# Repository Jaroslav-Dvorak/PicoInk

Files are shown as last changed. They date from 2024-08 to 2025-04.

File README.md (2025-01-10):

# PicoInk 

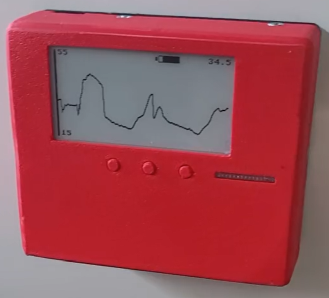
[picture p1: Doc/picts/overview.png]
overview


PicoInk byl vyvinutý za účelem měření fyzikálních veličin v místech, kde není třeba měřit velice často, ale postačuje jedno měření za 15 minut. Například: teplota, výška hladiny, koncentrace CO2, vlhkost půdy, vlhkost vzduchu, a podobně. Z této podstaty byl v návrhu kladen důraz na dlouhou výdrž baterie. 
Oproti podobným zařízením, které využívají deep-sleep režim mikrokontroléru, se zde o periodické měření stará externí časovací obvod [TPL5110](https://www.ti.com/lit/ds/symlink/tpl5110.pdf), který má v odpočítávací fázi téměř neměřitelnou spotřebu (35nA). 
Dalším prvkem, který přispívá k dlouhé výdrži baterie je e-inkový displej, který ze své technické podstaty zobrazuje informace, přestože je baterie odpojena. Za normálních okolností musí displej po připojení k napájení projít tzv. full-refreshem. Full-refresh není příliš estetická záležitost a je také energeticky náročná. Tyto důvody vedly k vývoji knihovny obsluhující displej s možností částečného překreslení i bez full-refreshe.
Horizontální rozlišení použitelného e-ink displeje je 250 pixelů. Pokud využijeme displej k vykreslení průběhu naměřených hodnot, přičemž každá hodnota zabere jeden pixel, můžeme vykreslit historii v grafu v délce necelých tří dnů, konkrétně 62,5 hodin.\
**To z něj v dělá jedinečný bateriový teploměr schopen nepřetržitého zobrazení historie hodnot v grafu.**
Jelikož je mozkem celého zařízení mikrokontrolér Raspberry Pi Pico W, dostupná je konektivita ve formě Bluetooth Low Energy a 2.4GHz WiFi. 
Pro zasílání naměřených hodnot přes Bluetooth byl zvolen otevřený protokol BTHome, ve formě pasivních advertisement zpráv. Důvodem je skvělá kompatibilita a super-rychlá integrace v Home Assistant.
V případě využití WiFi byl zvolen protokol MQTT, který lze rovněž vcelku jednoduše zaintegrovat do Home Assistant systému.\
**Výdrž baterie Liitokala 3500mAh s použitím teplotního a vlhkostního snímače SHT41 s vypnutým vyhříváním a připojení k WiFi s kvalitním signálem byla naměřena na 6 měsíců, cca 10000 měření.**
Baterií je myšlen akumulátor typu 18650, který je možno dobít přes USB-C konektor.
Pro rychlou výměnu lze baterii vyjmout a nahradit baterií čerstvě nabitou.

PicoInk je fyzicky složen ze dvou částí:
* Hlavní část obsahující elektroniku, baterii, displej a desku spojů.
* Modul, který je odnímatelný. Podle jeho typu zařízení plní svůj účel - zde je umístěn snímač.

Spojení mezi těmito částmi zajišťuje konektor, přes který lze modul napájet. Buďto z 3.3V zdroje mikrokontroléru nebo přímo z baterie. 
Dále obsahuje piny, jenž lze použít pro analogové měření nebo sběrnice UART, SPI, I2C, OneWire (viz.doc).
PicoInk je možné po úpravě software využívat i bez modulu. Například pro zobrazování online dat.

**V současné době jsou plně vyvinuty dva moduly - snímač teploty pro horizontální a vertikální bojler.**\
Avšak PicoInk byl otestován a má softwarovou přípravu na: 
* Snímač CO2 SCD41. Výdrž baterie klesla na jeden měsíc (s WiFi).
* Analogový snímač pro kapacitní měření vlhkosti půdy. Vlhkost klesá velmi pomalu, graf je krátký.
* Teplotní a vlhkostní snímač DHT22, měření snímače trvá různou dobu, někdy i velmi dlouho.
* Teplotní a vlhkostní snímač SHT41, vše OK.
* Teplotní snímač Dallas DS18B20, nutné použít originál, jinak vše OK.

**Známé bugy:**\
~~* Při delším vyjmutí baterie dojde k vybití vnitřního kondenzátoru. \
Při opětovném vložení nabitého článku dochází k proudové mikrošpičce. \
Z toho důvodu dojde k deaktivaci výstupu ochranného obvodu. \
Baterii je tedy nutno znovu vytáhnout a vložit. Ve zkratce - **baterii je někdy třeba vložit na dvakrát.**~~\
(Vyřešeno změnou hodnoty kondenzátoru C1 z 1uF na 100nF)

**TODO list:**
- [x] Moduly pro různé bojlery
- [x] Návod k použití pro normální lidi (pdf)
- [x] Tiskové instrukce (README.md ve složce 3D)
- [x] Instrukce ke stavbě zařízení (pdf)
- [x] Instrukce k výměně baterie a montáži/demontáži modulu (pdf)
- [x] Instrukce k naprogramování kontroléru (README.md ve složce Code)
- [x] Instrukce k výrobě PCB (README.md ve složce Electric)

[Zde](https://www.facebook.com/profile.php?id=61566121148711) mě můžete přímo kontaktovat.

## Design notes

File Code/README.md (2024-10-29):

### Instrukce pro naprogramování kontroléru

3. Připojit Rpi Pico W k PC pomocí microUSB kabelu.
2. Do kontroléru nahrát firmware [micropythonu](https://micropython.org/download/RPI_PICO/).
2. Použít k připojení k Rpi Pico W např. [Thonny](https://thonny.org) nebo PyCharm s Micropython pluginem.
3. Flash obsah celého (tohoto) adresáře "Code" do RpiPico W 
   * vyjma souboru README.md
   * můžeme také vynechat soubory ze složky sensors dle použitého typu senzoru.

### Výběr typu snímače
1. Ve složce sensors jsou k dispozici různé snímače.
2. V souboru sensor.py - import podle typu sensoru.
3. Dále definice správných pinů apod.

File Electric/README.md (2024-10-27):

### Výroba elektro: 
1. Objednávka součástek podle [partlistu](./Partlist.md).
2. Soubor **Gerber_PCB_PicoInk.zip** obsahuje výrobní data - zaslat soubor výrobci.
3. Osazení PCB podle schématu. 
[Video osazovnání](https://www.youtube.com/watch?v=MjlOoAGtTvY&list=PL2hwsy43ra5UZU4RDyN6xl_J_FKD02n1o) |
[Komentované video](https://www.youtube.com/watch?v=83LGPPGywaA)

### Editace projektu:
1. Registrace na [EasyEDA](https://easyeda.com).
2. V EasyEDA Std designeru vytvořit nový projekt.
3. File --> File Source --> vložit obsah souboru **SCH_PicoInk.json**
4. Design --> Convert Schematic to PCB --> Save
5. File --> File Source --> vložit obsah souboru **PCB_PicoInk.json**

### Schéma:
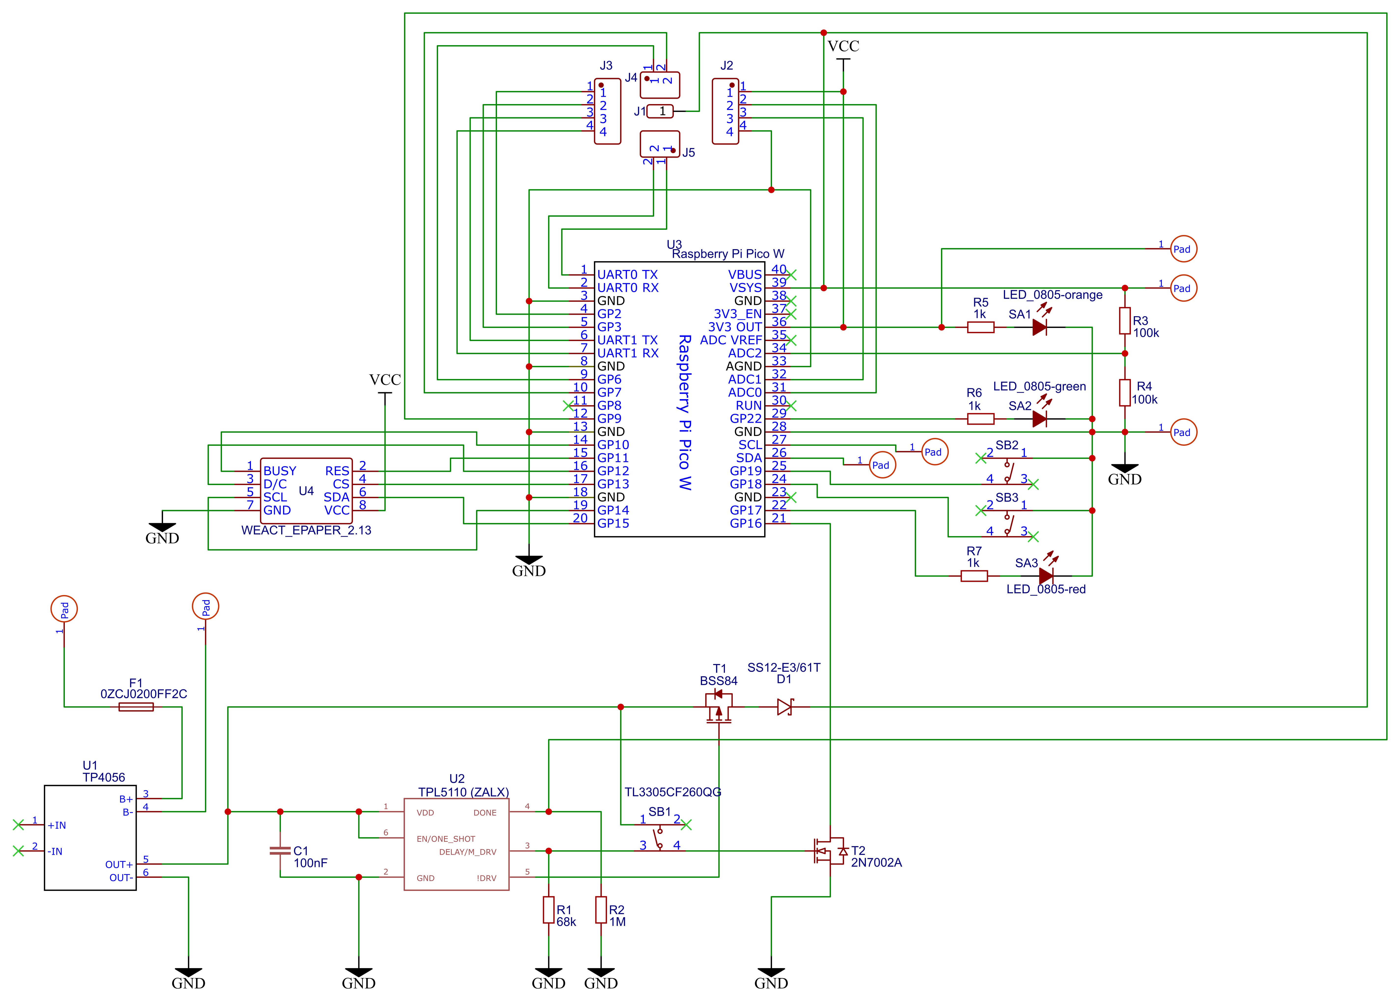
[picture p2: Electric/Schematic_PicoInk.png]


### Konektor:
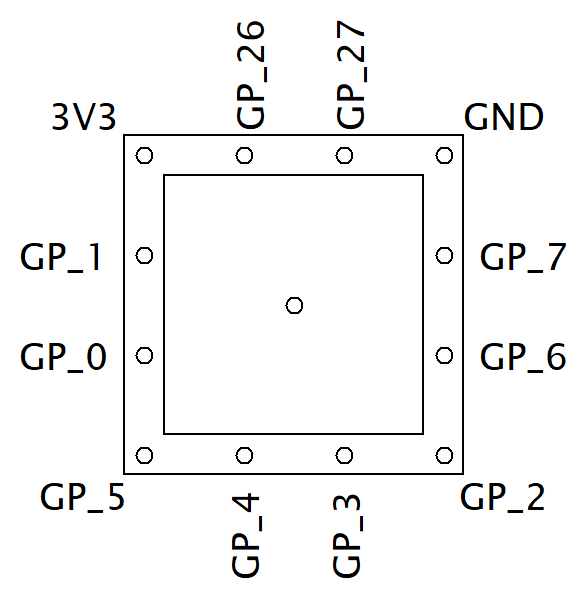
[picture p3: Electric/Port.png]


### PCB:
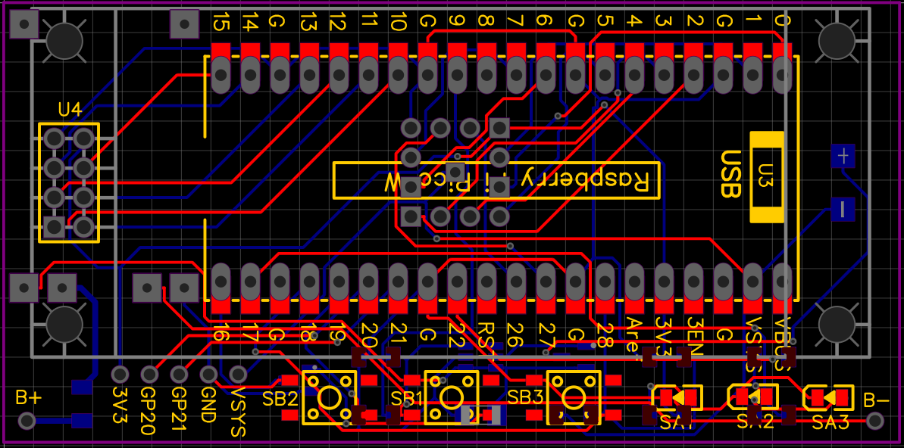
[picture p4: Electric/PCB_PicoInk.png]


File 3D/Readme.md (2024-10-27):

Model byl vytvořen ve FreeCADu, veškeré soubory jsou ve složce "FCStd model".\
Předpřipravené tiskové soubory 3mf byly vytvořeny v Bambu Studiu.\
Modely byly v úspěšně tisknuty na tiskárně Bambulab A1.\

* Základní část zařízení (**MainBody_BambuStudio.3mf**) obsahuje:
  * **main_body** - PLA filament, udává barvu zařízení, základní profil
  * **battery_cover** - PLA filament, doporučena stejná barva jako main_body, základní profil
  * **display_holder** - PLA filament, na barvě nezáleží, základní profil
  * **light_guide** - PETG transparentní, nutný brim

* Modul pro měření teploty Bojleru Dražice (**Modul_Drazice_BambuStudio.3mf**):
    * **spring** - PETG, na barvě nezáleží, základní profil, doporučen 3D Lack
    * **modul** - PETG, barva zadní části zařízení
      * nutný brim
      * tisknout diagonálně
      * manuální supporty podle obrázku
      * variabilní výška vrstvy podle obrázku (0.2 --> 0.12)
      * teplota trysky 260°C

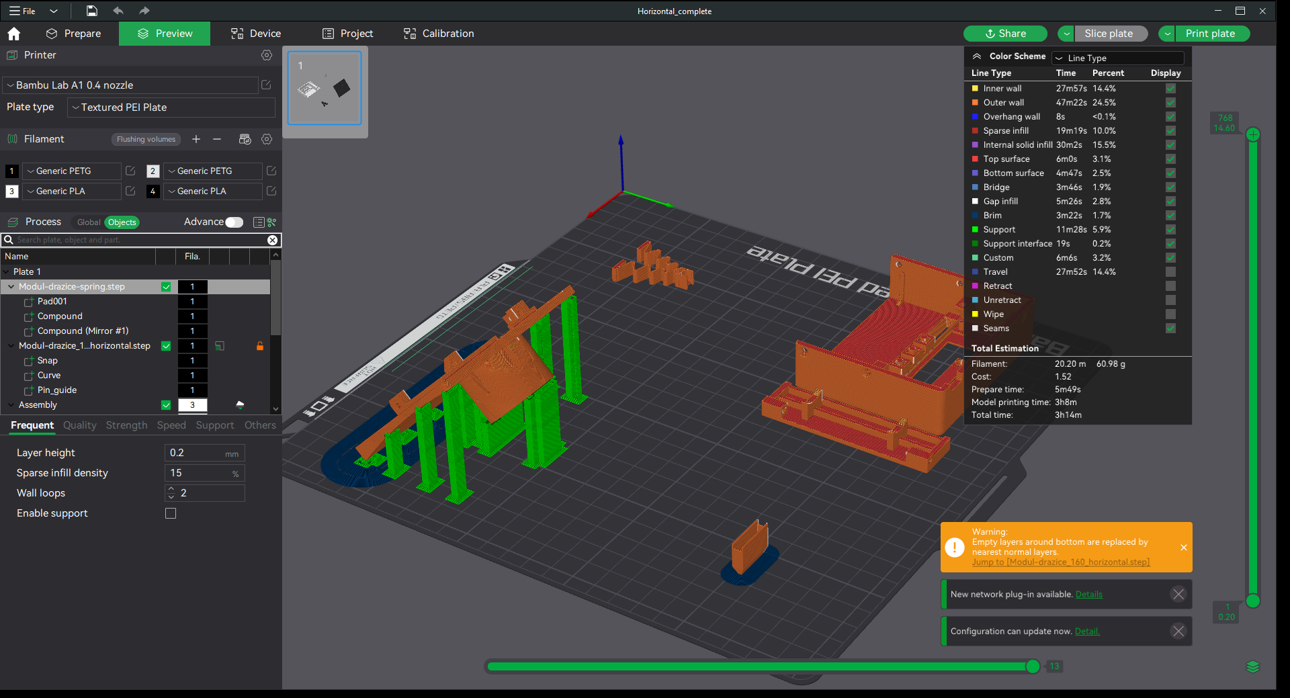
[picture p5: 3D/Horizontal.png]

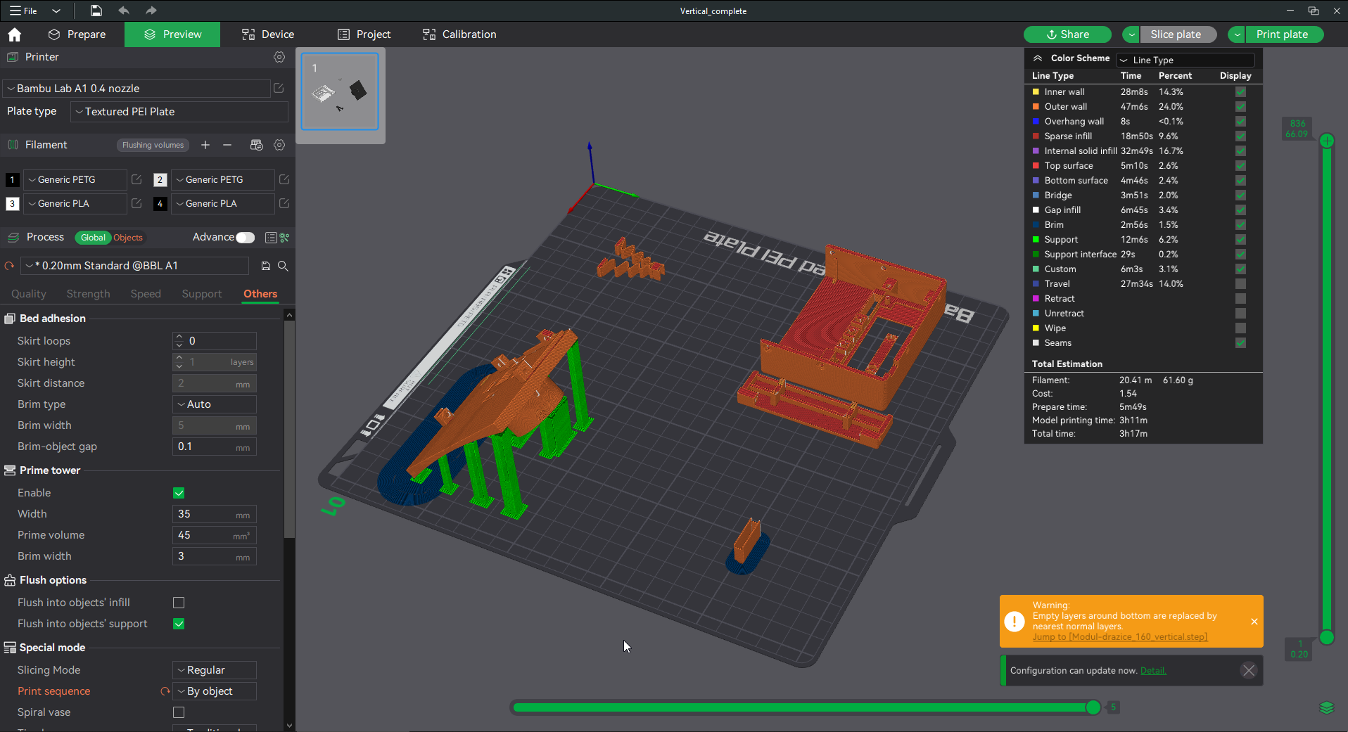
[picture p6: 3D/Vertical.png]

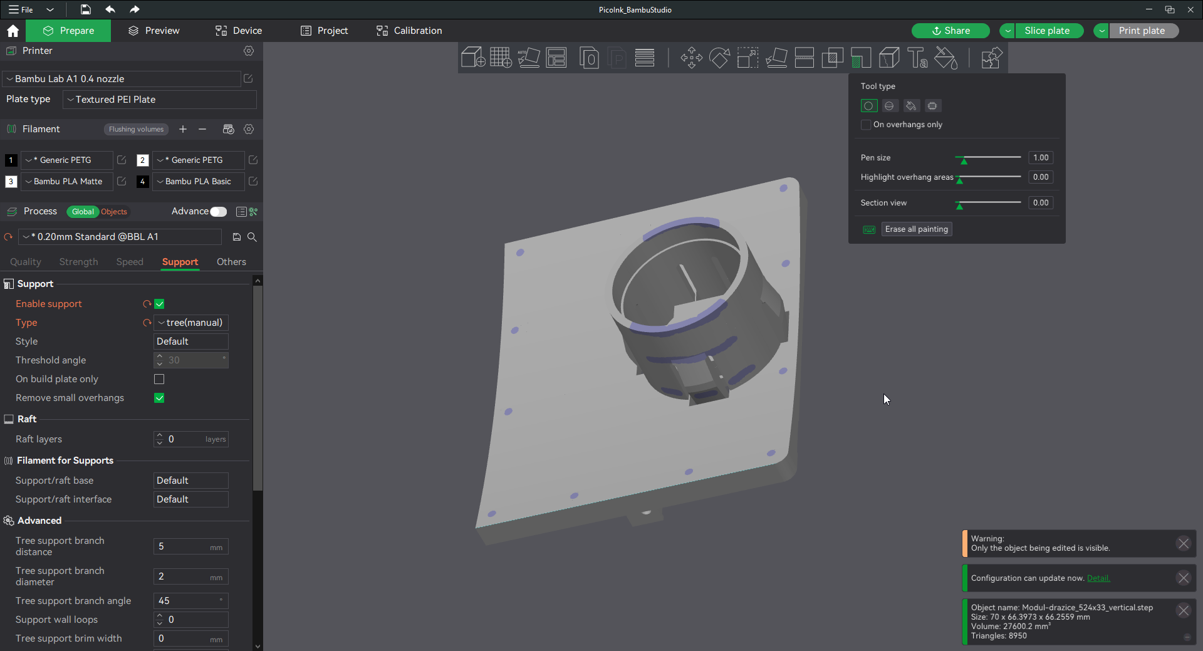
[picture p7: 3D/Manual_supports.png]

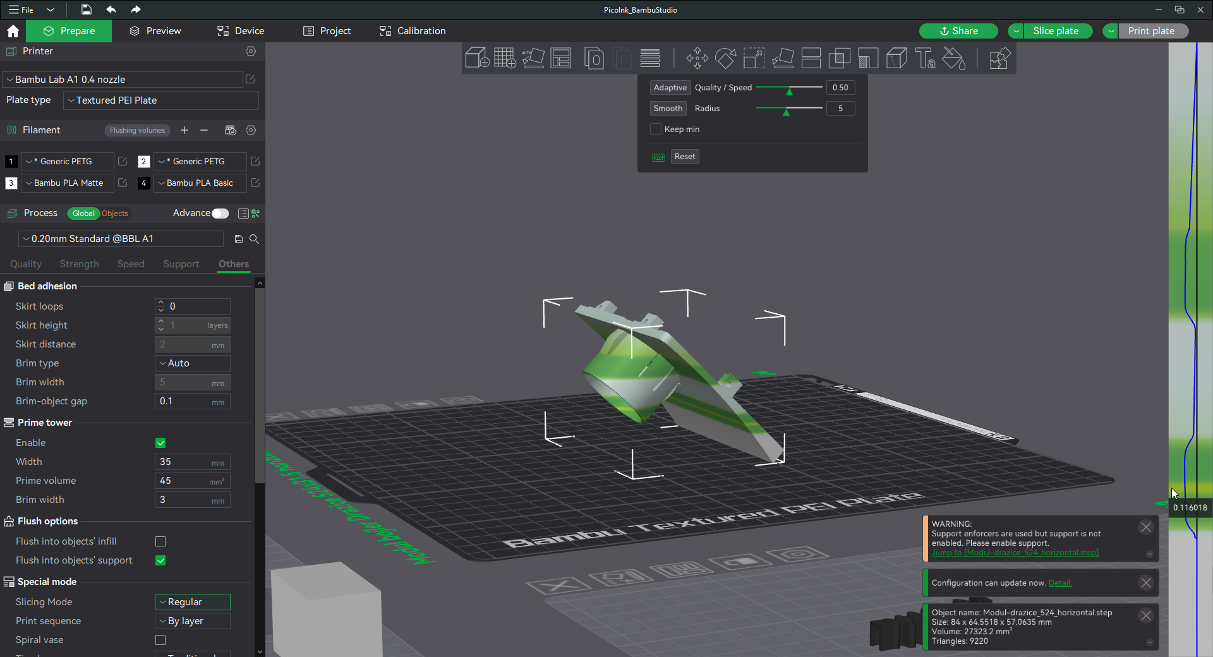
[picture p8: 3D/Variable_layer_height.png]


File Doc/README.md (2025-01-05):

[Manuál - Popis a obsluha zařízení](./PicoInk_control_manual_cs.pdf)\
[Manuál - MQTT nastavení](./PicoInk_MQTT_cs.pdf)\
[Manuál - Stavba zařízení](./PicoInk_assembly_cs.pdf)\
[Manuál - Instalační manuál](./PicoInk_installation_manual_cs.pdf) \
[Video - nastavení zařízení](https://fb.watch/vx8vt5eCgY/)\
[Video - stavba zařízení](https://www.youtube.com/watch?v=83LGPPGywaA)

## Rychlé uvedení do provozu

1. Ujistěte se, že je zařízení funkční. 
   * Krátkým stiskem prostředního tlačítka spustíme běžný cyklus.
   * Stavová LED se rozsvítí oranžově, poté problikne zelená a LED zhasne.
2. Proveďte mechanickou instalaci dle typu modulu.
    * **Modul měření teploty bojleru:**
      * Ujistěte se, že díra připravená pro teploměr je do dostatečné hloubky zbavená přebytečné izolační pěny.
      * Celé zařízení vtlačte do bojleru.
3. Dvojklikem a následným držením prostředního tlačítka vyberte vyhovující grafické zobrazení naměřené hodnoty.
4. Zvažte typ datového připojení. 
   * **Bluetooth Low Energy** s protokolem [BTHome](https://bthome.io):
     * Několikanásobně nižší spotřeba a tím vyšší výdrž baterie.
     * Velmi snadná konfigurace i integrace do Home Assistanta.
     * Žádná zpětná vazba (PicoInk nehlásí žádný problém, pokud datová zpráva nedorazí).
     * Datové zprávy nejsou šifrované a je možné je jednoduše odchytit v okolí senzoru.
   * **WiFi** s protokolem [MQTT](https://mqtt.org):
     * Baterie s kapacitou 3500mAh vydrží zaslání cca 10000 zpráv. Při 15 minutovém intervalu je to cca půl roku.
     * Při nezdařeném odeslání zařízení červeně blikne a na displeji informuje o problému.
     * V zařízení jsou zapsána hesla WiFi a Home Assistanta. Hesla lze vyčíst pomocí kabelového připojení k procesoru.
5. Spusťte nastavovací režim dlouhým podržením levého tlačítka a současným krátkým stiskem prostředního tlačítka.
   * Připojte se k nově vytvořené WiFi (PICOINK) telefonem nebo počítačem.
   * V případě telefonu, naskenujte zobrazený QR kód a potvrďte přesměrování.
   * V případě PC, zadejte do prohlížeče zobrazenou IP adresu (192.168.4.1).
6. Nastavte hodnoty. **Každou změnu je nutno potvrdit tlačítkem Write**.
   * Minimum a Maximum - ovlivňují pouze zobrazení na samotném zařízení (rozsah grafu nebo stupnice).
   * **Bluetooth Low Energy** varianta:
     * Vyplňte pole označené jako BLE-name (název zařízení - např. "bojler").
     * Kliněte na tlačítko Save and restart a zavřete nastavovací stránku.
     * V notifikacích Home Assistantu se zobrazí hlášení o nalezeném novém zařízení. Potvrdíme nakonfigurování do HA.
     * V zařízeních --> BTHome --> můžeme zapnout skrytou entitu signal.
   * **Wifi** varianta:
     * V Home Assistant musí být funkční MQTT integrace. Pokud není postujte podle [tohoto návodu](./PicoInk_MQTT_cs.pdf).
     * **Wifi-SSID** - Název WiFi sítě na kterou se má teploměr připojovat.
     * **WiFi-passw** - WiFi heslo.
     * **WiFi-IP** - nechat prázdné. *Pouze pro zkušené: Statická IP - formát CIDR. Pokud je prázdné, DHCP přidělení.*
     * **MQTT-broker** - IP adresa serveru Home Assistanta (MQTT brokera) nebo jeho DNS název.
     * **MQTT-user** - uživatelské jmeno některého z uživatelů Home Assistanta.
     * **MQTT-passw** - heslo výše zadaného uživatele.
     * **MQTT-name** - název zařízení (součást názvu entit v Home Assistant).
     * Kliněte na tlačítko Save and restart a zavřete nastavovací stránku.
     * Počkejte až zhasne stavová LED.
     * Dlouhým požením pravého tlačítka a současným krátkým stiskem prostředního tlačítka spusťte testovací režim.
     * Pokud hlášení končí "Everything is ok..:-)" V Home Assistantu přibylo nové zařízení s potřebnými entitami.

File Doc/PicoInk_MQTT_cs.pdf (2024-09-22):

Krok 0: Správně by měl být HA Server (RaspberryPi) do routeru připojený kabelem a měl v routeru zafixované přiřazení IP, aby byla pro server vždy přiřazena stejná. V praxi router přiřazuje pořád dokola stejné IP podle MAC, ale není to garantované. Každý router se nastavuje jinak, nelze udělat přesný návod. Většinou je to nějaké zatrhávátko v klient listu.
Krok 1 - Home Assistant Nastavení:
- Dokonči prvotní nastavení HA (jméno, heslo, atd..) a nainstaluj a spusť doplněk MQTT:
- Nastavení → Doplňky → Obchod s dopňky → Mosquitto Broker → Nainstalovat
- Hlídací pes ZAP → Spustit při spuštění ZAP → Spustit

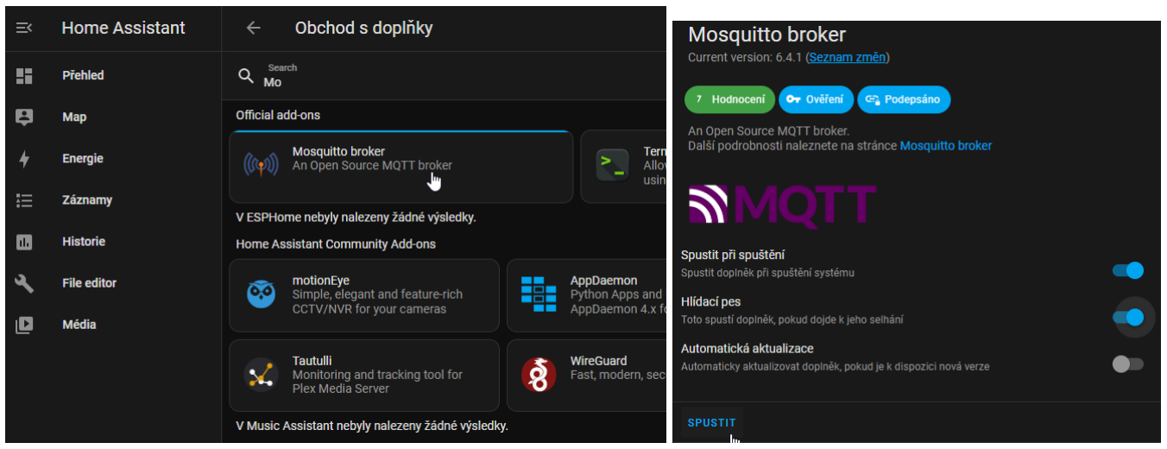
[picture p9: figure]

- Zaintegruj nainstalovaný MQTT doplněk mezi zařízení:
- Nastavení → Zařízení a služby → MQTT NASTAVIT → ODESLAT

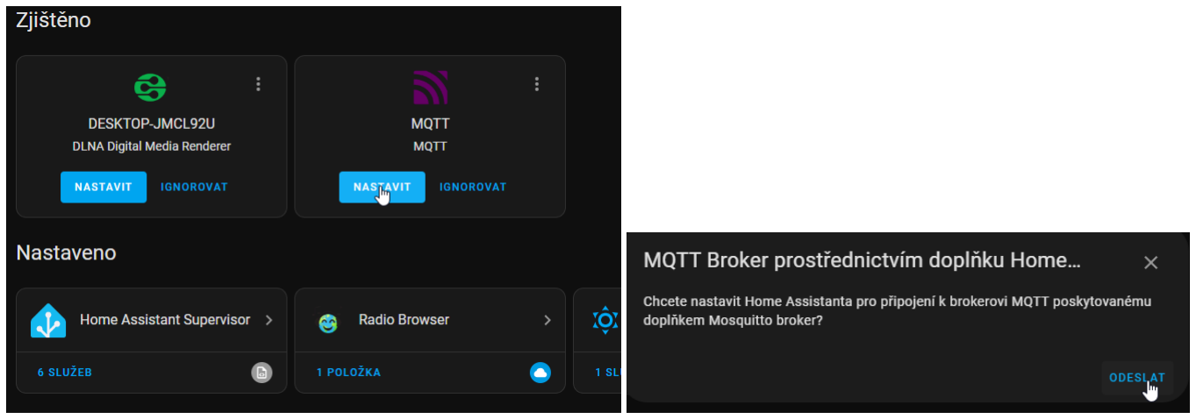
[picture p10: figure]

- Pokud neskončí hlášení hláškou “Úspěch”, chvíli vyčkej a zkus znovu, klidně víckrát.
- Zjisti si IP Home Assistanta.
- I když k HA lze přistupovat přes lokální DNS název homeassistant.local, je lepší do snímače nastavit lokální IP serveru. Je to spolehlivější a i úspornější pro baterii.
- Adresa se dá zjistit spousty způsoby, například v HA:
- Nastavení → Systém → Síť → tři tečky → Informace o IP

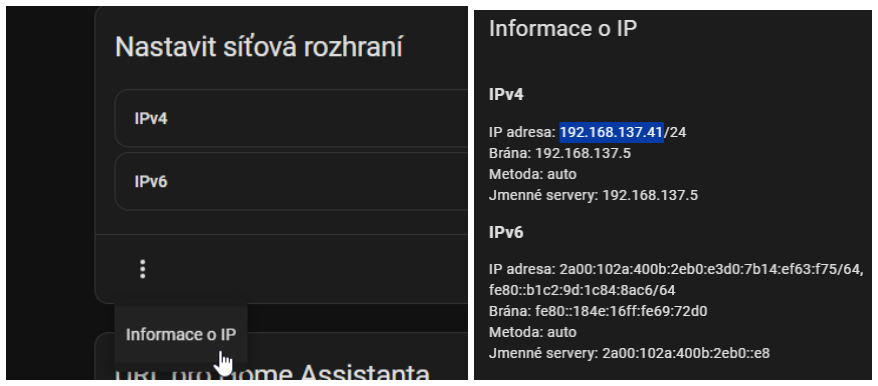
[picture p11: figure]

Krok 2 - Nastav teploměr:
- Podrž a stále drž levé tlačítko a k tomu krátce stiskni prostřední tlačítko. LED by měla svítit žlutě. Levé tlačítko stále drž, dokud se neobjeví na displeji informace a QR kód.
- Připoj se telefonem nebo počítačem k WiFi pojmenované podle informace SSID (PICOINK).
- Telefon se možná po chvíli zeptá, jestli chceš zůstat připojený. Potvrď, že ano - vždy.
- Pokud používáš telefon, načti QR kód a potvrď přesměrování na Web.
- Pokud používáš PC, otevři prohlížeč a do adresního řádku přepiš IP (192.168.4.1).
- Displej by měl vypsat nové informace a v prohlížeči by se měl zobrazit formulář.
- Při každé změně textového pole klikneme na tlačítko WRITE vedle pole, změna se vždy musí projevit na displeji teploměru.
- Pokud by se změny přestaly přepisovat nebo teploměr přestal reagovat, stiskneme krátce levé tlačítko, teploměr se restartuje a začneme znovu.
- zde můžeme posunout výslednou hodnotu do plusu i do mínusu. Pro případ jakési kalibrace.
- Vrchní zastropování grafu nebo maximální hodnota rafičky.
- Spodní dno grafu nebo minimální hodnota rafičky.
- Název WiFi sítě na kterou se má teploměr připojovat. Pokud nechceme využít WiFi a MQTT, necháme prázdné.
- WiFi heslo. Teploměr podporuje pouze WPA2 nebo otevřenou sít. Pokud máme otevřenou, necháme prázdné.
- Možnost statické WiFi teploměru ve formátu CIDR. Pokud chceme využívat DHCP, necháme prázdné (většinou ano).
- Zde vepíšeme IP Home Assistanta, kterou jsme si zjistili v předchozím kroku.
- Uživatelské jméno některého uživatele Home Assistanta. Doporučen je prvotní, kterého jsme zadali při prvním startu.
- Heslo uživatele v HA zadaného v předchozím poli.
- Název našeho zařízení, jak se bude v HA jmenovat.
- Možnost vysílání zpráv přes BLE. V kombinaci s MQTT nemá smysl, necháme volné. Můžeme však vyzkoušet, zda nebude BLE stačit - větší životnost baterie, stačí vyplnit název, jak se má v HA jmenovat.
- Jakmile máme vše nastavené, informace vidíme i na díspleji, potvrdíme zde a zavřeme stránku.

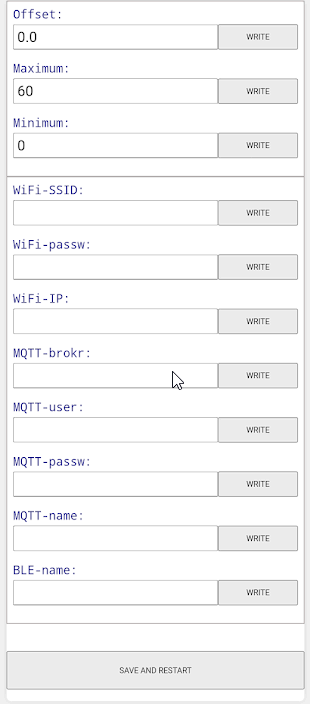
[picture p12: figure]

Hesla pro WiFi a HA uživatele jsou uloženy v teploměru nezabezpečeně. Z principu je zabezpečit nelze. Pokud se dostane teploměr někomu šikovnému do ruky a do USB portu počítače, může vaše hesla zjistit.

Krok 3 - ahoj, já jsem teploměr:
- Mohlo by se zdát, že v tuto chvíli už je všechno hotovo. Pokud jsme si všimli po nastavování a následném restartu krátkého zeleného probliknutí, máme v podstatě vyhráno. Znamená to, že se teploměr úspěšně připojil, navázal spojení s HA, zaslal data, odpojil se a vypnul se. Znovu to udělá za 15 minut.
- Data ovšem v HA (skoro) nikde nenajdeme. To protože musíme nejdříve nechat teploměr do HA zaslat konfigurační zprávu, aby bylo jasné, jak s daty z teploměru nakládat (třeba °C nebo % baterie apod.).
- Stiskneme a držíme pravé tlačítko a krátce stiskneme prostřední tlačítko. Čekáme a držíme pravé, dokud displej nezačne vypisovat informace.
- Pokud je něco v nepořádku, zjistíme to zde. Vidíme postupné připojení na WiFi a na MQTT.
- Na konci procedury by mělo být vypsáno “sending discovery message”. Od této chvíle bychom měli v HA vidět nové entity - teplotu, signál, stav baterie a jejich hodnoty.

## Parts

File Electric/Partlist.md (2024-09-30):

| description | item code | amount | supplier | czech description |
|---|---|:---:|---|---|
| Custom PCB | PCB | 1 | [jlcpcb.com](http://jlcpcb.com/) | plošný spoj |
| Rpi pico w controller | [RPI007](https://rpishop.cz/raspberry-pi-pico/5073-raspberry-pi-pico-w.html) | 1 | [rpishop.cz](http://rpishop.cz/) | kontrolér |
| Battery holder | [1653557483](https://dratek.cz/arduino/122966-bateriovy-box-1x-18650-dps-dil.html) | 1 | [dratek.cz](http://dratek.cz/) | Pouzdro baterie |
| WeAct E-ink 2.13 BW | [1005004644515880](https://www.aliexpress.com/item/1005004644515880.html) | 1 | [aliexpress.com](http://aliexpress.com/) | zobrazovač |
| Timer TPL 5110 | [33047272643](https://www.aliexpress.com/item/33047272643.html) | 1 | [aliexpress.com](http://aliexpress.com/) | časovač |
| TP 4056-18650 TYPE-C | [1005001636470790](https://www.aliexpress.com/item/1005001636470790.html) | 1 | [aliexpress.com](http://aliexpress.com/) | nabíječka | 
| Liitokala Battery 3500mAh  | [1005004189084125](https://www.aliexpress.com/item/1005004189084125.html) | 1 | [aliexpress.com](http://aliexpress.com/) | baterie | 
| Pin header L35mm A3mm B6mm | [32797801506](https://www.aliexpress.com/item/32797801506.html) | 1 | [aliexpress.com](http://aliexpress.com/) | hřebínek | 
| Capacitor 1uF | [C1206C105K3RAC](https://www.tme.eu/cz/en/details/c1206c105k3rac/mlcc-smd-capacitors/kemet/c1206c105k3ractu/) | 1 | [tme.cz](http://tme.cz/) | kondenzátor |
| Resistor 68k | [WR12X6802FTL](https://www.tme.eu/cz/en/details/wr12x6802ftl/smd-resistors/walsin/) | 1 | [tme.cz](http://tme.cz/) | rezistor | 
| Resistor 1M | [SMD1206-1M](https://www.tme.eu/cz/en/details/smd1206-1m/smd-resistors/royal-ohm/1206s4j0105t5e/) | 1 | [tme.cz](http://tme.cz/) | rezistor | 
| Resistor 100k | [SMD0805-100K-1%](https://www.tme.eu/cz/en/details/smd0805-100k-1%25/smd-resistors/royal-ohm/0805s8f1003t5e/) | 2 | [tme.cz](http://tme.cz/) | rezistor | 
| Resisitor 1k | [CRCW12061K00JNTABC](https://www.tme.eu/cz/en/details/crcw12061k00jntabc/smd-resistors/vishay/) | 3 | [tme.cz](http://tme.cz/) | rezistor | 
| N-CH Mosfet | [2N7002-DIO](https://www.tme.eu/cz/details/2n7002-dio/tranzistory-s-kanalem-n-smd/diotec-semiconductor/2n7002/) | 1 | [tme.cz](http://tme.cz/) | N-CH mosfet | 
| P-CH Mosfet | [LGE2305-LGE](https://www.tme.eu/cz/details/lge2305-lge/tranzistory-s-kanalem-p-smd/luguang-electronic/lge2305/) | 1 | [tme.cz](http://tme.cz/) | P-CH mosfet | 
| Shottky diode | [SS12-E3/61T](https://www.tme.eu/cz/en/details/ss12-e3_61t/smd-schottky-diodes/vishay/) | 1 | [tme.cz](http://tme.cz/) | dioda | 
| Poly-Fuse 2A | [0ZCJ0200FF2C](https://www.tme.eu/cz/details/0zcj0200ff2c/polymerove-pojistky-smd/bel-fuse/) | 1 | [tme.cz](http://tme.cz/) | pojistka | 
| Button | [TL3305CF260QG](https://www.tme.eu/cz/details/tl3305cf260qg/mikrospinace-tact/e-switch/) | 3 | [tme.cz](http://tme.cz/) | tlačítko | 
| Sensor socket | [ZL262-3SG](https://www.tme.eu/cz/en/details/zl262-3sg/pin-headers/connfly/ds1023-1-3s21/) | 4 | [tme.cz](http://tme.cz/) | zásuvka 3-pin | 
| Display socket | [ZL262-8DG](https://www.tme.eu/cz/en/details/zl262-8dg/pin-headers/connfly/ds1023-2-4s21/) | 3 | [tme.cz](http://tme.cz/) | zásuvka 6-pin | 
| LED 0805 orange | [LL-S170UYC-Y2-1B](https://www.tme.eu/cz/details/ll-s170uyc-y2-1b/diody-led-smd-barevne/luckylight/) | 1 | [tme.cz](http://tme.cz/) | LED oranžová | 
| LED 0805 green | [RF-GSB170TS-BC](https://www.tme.eu/cz/en/details/rf-gsb170ts-bc/smd-colour-leds/refond/) | 1 | [tme.cz](http://tme.cz/) | LED zelená | 
| LED 0805 red | [RF-RUB170TS-BD](https://www.tme.eu/cz/en/details/rf-rub170ts-bd/smd-colour-leds/refond/) | 1 | [tme.cz](http://tme.cz/) | LED červená | 
| Temperature sensor | [DS18B20+](https://www.tme.eu/cz/en/details/ds18b20+/temperature-transducers/analog-devices-maxim-integrated/) | 1 | [tme.cz](http://tme.cz/) | snímač teploty | 
| Screws | [M2.5X10/D965B](https://www.tme.eu/cz/en/details/m2.5x10_d965b/bolts/kraftberg/) | 9 | [tme.cz](http://tme.cz/) | šrouby |
| Sensor PCB | [24709](http://www.hezkyden.cz/shop/bastldeska-kulata-profi-jednostranna/) | 1 | [hezkyden.cz](http://hezkyden.cz/) | bastldeska kulatá |

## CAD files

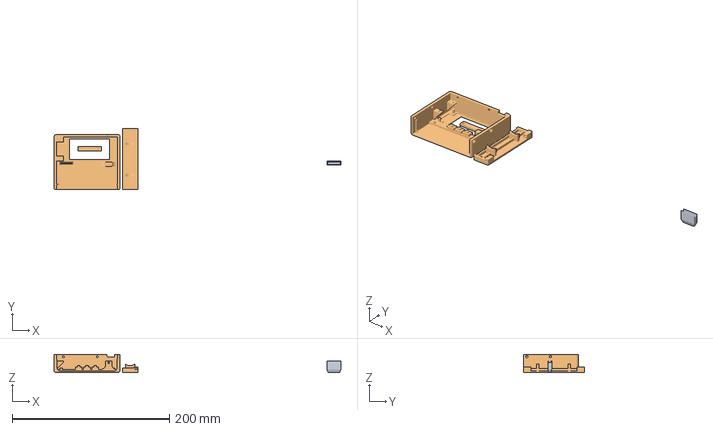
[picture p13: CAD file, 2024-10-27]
3D/MainBody_BambuStudio.3mf
364.8 x 78.0 x 23.0 mm
Light_guide.step
Assembly

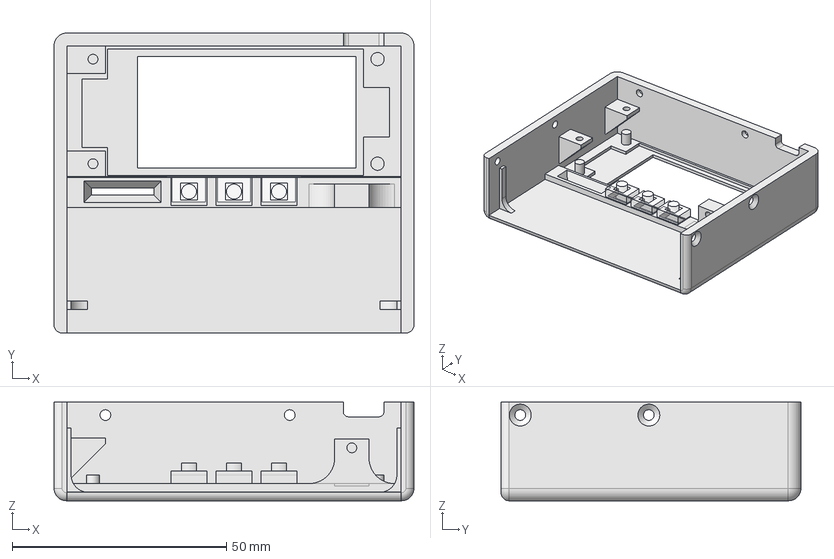
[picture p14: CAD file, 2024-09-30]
3D/FCStd model/Main_body.FCStd
84.0 x 70.0 x 23.0 mm
Screen
Buttons
Bottom
Wall

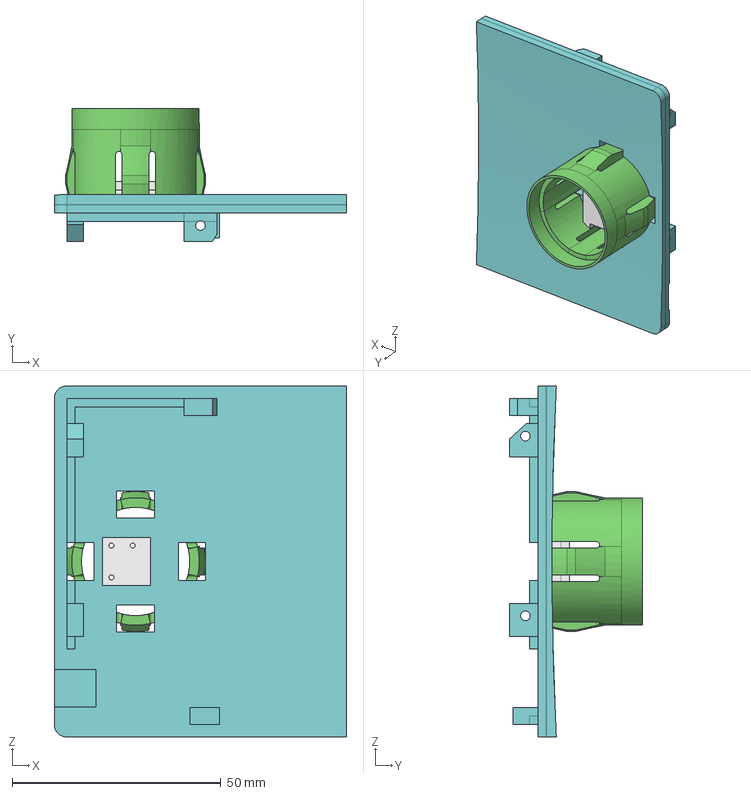
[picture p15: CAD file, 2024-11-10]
3D/FCStd model/Modul-drazice_1650x30_OKH 100 NTR.FCStd
70.0 x 31.8 x 84.0 mm
Snap
Curve
Pin_guide

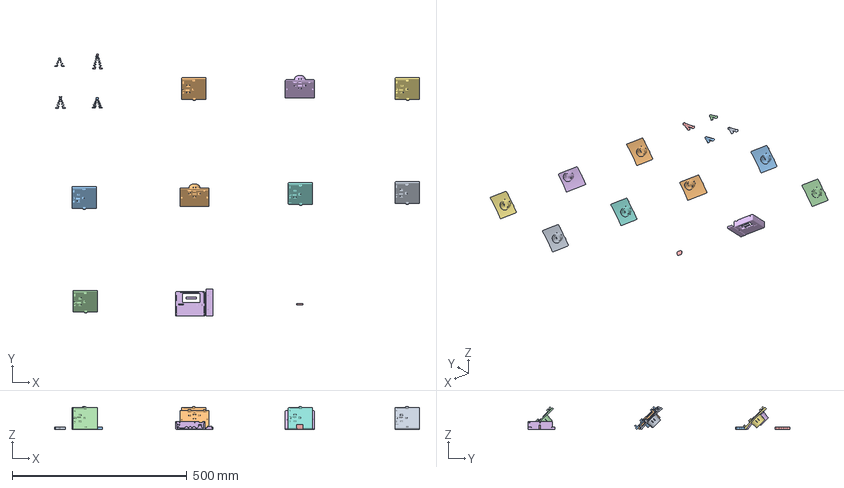
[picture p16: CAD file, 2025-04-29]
3D/PicoInk.3mf
1044.5 x 750.2 x 66.3 mm
Modul-drazice-spring.step
Modul-drazice_160_vertical.step
Modul-drazice_spring_47.step
Modul-drazice-spring_42.step
Modul-drazice_spring_60.step
Modul-drazice_524_horizontal.step
Modul-drazice_524x33_vertical.step
Modul-drazice_600_vertical.step
Modul-drazice_650_vertical.step
Modul-drazice_584_horizontal.step
Assembly x 2
Modul-drazice_828x30_vertical.step
Light_guide.step

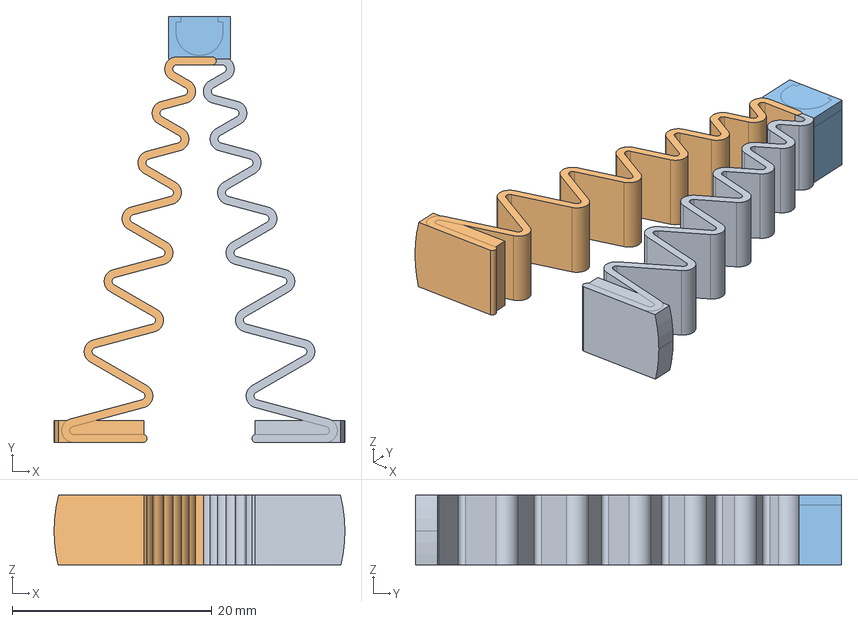
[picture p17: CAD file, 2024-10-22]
3D/FCStd model/Modul-drazice_spring_60.FCStd
29.1 x 42.6 x 7.00 mm
Compound (Mirror #1)

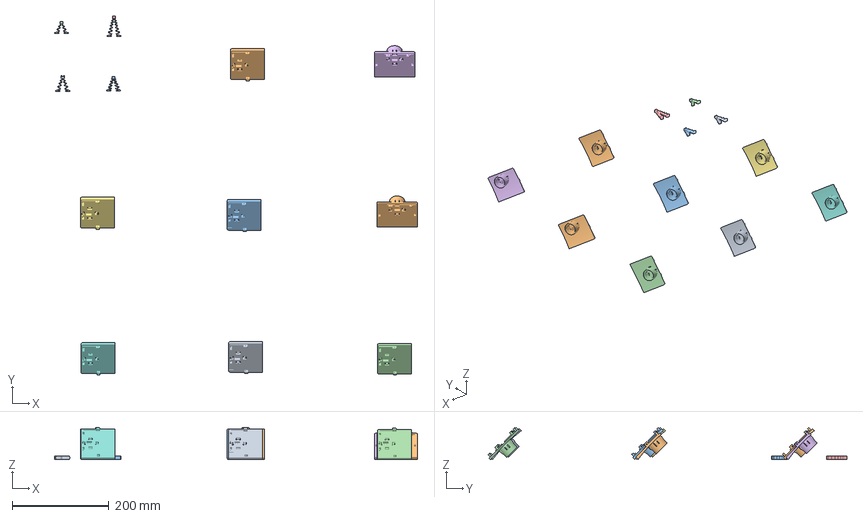
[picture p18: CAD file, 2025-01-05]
3D/Modul_Drazice_BambuStudio.3mf
749.7 x 741.2 x 66.3 mm
Modul-drazice-spring.step
Modul-drazice_160_vertical.step
Modul-drazice_spring_47.step
Modul-drazice-spring_42.step
Modul-drazice_spring_60.step
Modul-drazice_524_horizontal.step
Modul-drazice_524x33_vertical.step
Modul-drazice_600_vertical.step
Modul-drazice_650_vertical.step
Modul-drazice_584_horizontal.step
Assembly
Modul-drazice_828x30_vertical.step

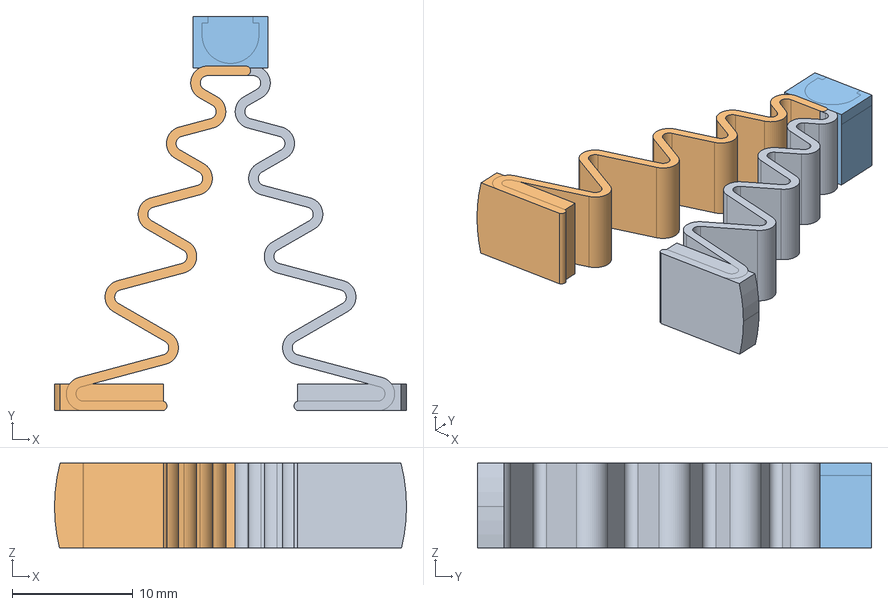
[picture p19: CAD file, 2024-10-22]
3D/FCStd model/Modul-drazice_spring_50.FCStd
29.1 x 32.6 x 7.00 mm
Compound (Mirror #1)

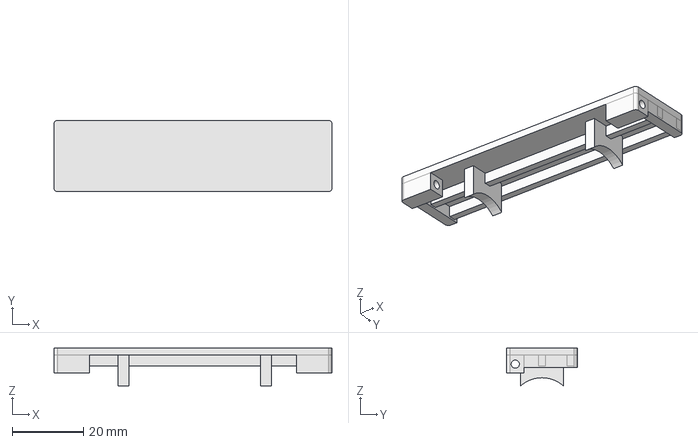
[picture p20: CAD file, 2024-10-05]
3D/FCStd model/Battery_cover.FCStd
78.0 x 20.0 x 10.6 mm

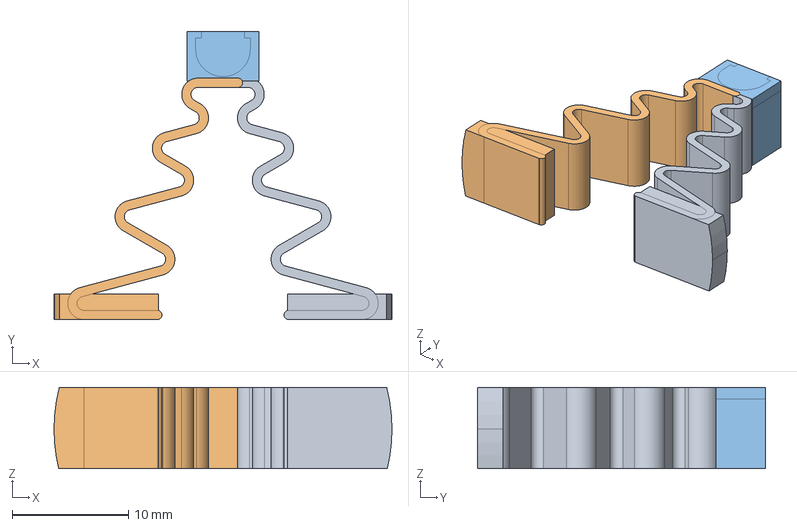
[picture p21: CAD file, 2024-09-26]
3D/FCStd model/Modul-drazice-spring_42.FCStd
29.1 x 24.8 x 7.00 mm
Compound (Mirror #1)

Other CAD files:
3D/Box_V3.step
3D/FCStd model/Modul-drazice_670_vertical.FCStd
3D/FCStd model/Modul-drazice_524x33_vertical.FCStd
3D/Modul-bojler_horizontal_V2.step
3D/FCStd model/Modul-drazice_584_horizontal.FCStd
3D/FCStd model/Modul-drazice_600_vertical.FCStd
3D/FCStd model/Modul-drazice_650_vertical.FCStd
3D/FCStd model/Modul-drazice_584_vertical.FCStd
3D/FCStd model/Modul-drazice_524_horizontal.FCStd
3D/FCStd model/Display_holder.FCStd
3D/FCStd model/Light_guide.FCStd
3D/FCStd model/Modul-drazice_524_vertical.FCStd
3D/FCStd model/Modul_base.FCStd

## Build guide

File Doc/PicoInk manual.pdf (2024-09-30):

# Základní popis prvků:

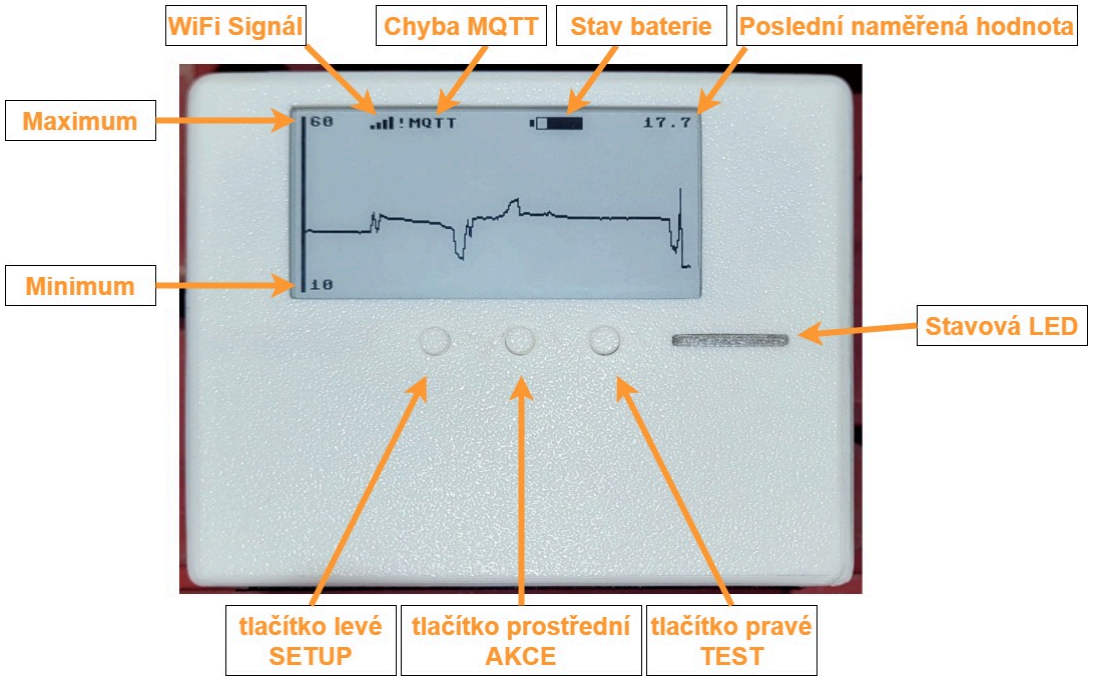
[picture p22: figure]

Ovládání:
Zařízení se ovládá pomocí tří tlačítek a subjektivně se může jevit jako neintuitivní. Z podstaty hardwarové topologie musí být zařízení ovládáno následujícím způsobem:
- tlačítko AKCE probouzí zařízení na povel. Zařízení se také probouzí samo v 15cti minutovém intervalu.
- po probuzení si zařízení zjišťuje stav ostatních tlačítek, včetně samotného tlačítka AKCE.
- pokud není žádné jiné tlačítko stisknuto, zařízení provede běžné měření a opět se uspí.
- reakce na stisk tlačítek je velmi pomalá, je třeba trpělivě vyčkat.

Stavová LED:
- Svítí žlutě (oranžově) ve chvíli, kdy je zařízení probuzené (probíhá měření, nastavování, apod.).
- Krátce blikne zeleně na konci měřícího a odesílacího cyklu v případě, že vše proběhlo v pořádku.
- Krátce blikne červeně na konci měřícího a odesílacího cyklu v případě nějakého problému.
- Žádné spojení s čidlem, slabá baterie, nepřipojená WiFi, apod.

Režimy zařízení:
- Nastavovací režim: slouží k nastavení např. Maximum a Minimum hodnot nebo datovému připojení.
- Testovací režim: slouží k diagnostice zařízení a připojení a také k zaslání discovery message do HA.
- Přepínání obrazovek: slouží ke změně grafického zobrazení naměřených dat na e-ink displeji.
- Režim běžného měření: spouští se v 15cti minutovém intervalu nebo krátkým stiskem tlačítka AKCE.
- Režim továrního nastavení: v tomto režimu lze smazat veškeré konfigurační a logovací soubory.

# Nastavovací režim:

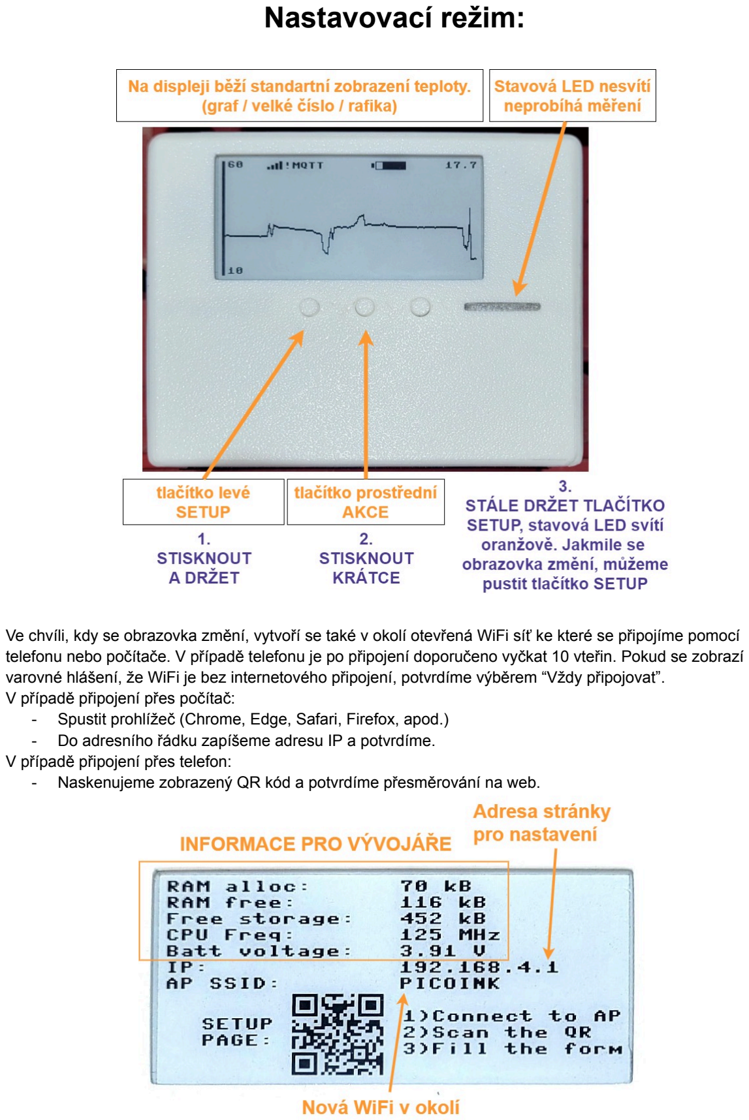
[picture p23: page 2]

Ve chvíli, kdy se obrazovka změní, vytvoří se také v okolí otevřená WiFi síť ke které se připojíme pomocí telefonu nebo počítače. V případě telefonu je po připojení doporučeno vyčkat 10 vteřin. Pokud se zobrazí varovné hlášení, že WiFi je bez internetového připojení, potvrdíme výběrem “Vždy připojovat”.
V případě připojení přes počítač:
- Spustit prohlížeč (Chrome, Edge, Safari, Firefox, apod.)
- Do adresního řádku zapíšeme adresu IP a potvrdíme.
V případě připojení přes telefon:
- Naskenujeme zobrazený QR kód a potvrdíme přesměrování na web.

Po úspěšném připojení prohlížeče k PicoInku, se na displeji zařízení zobrazí nastavené parametry. V telefonu nebo počítači se zobrazí stránka s odpovídajícími textovými poly.

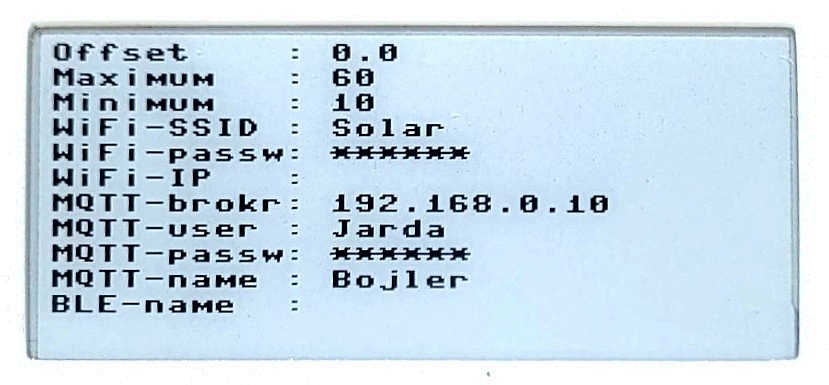
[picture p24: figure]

Nyní můžeme parametry měnit. Po každé změně parametru je nutné kliknout na tlačítko WRITE a zkontrolovat, jestli se změna projevila i na displeji PicoInku.

Offset posune výslednou hodnotu měření.

Maximální hodnota pro zobrazení grafu nebo rafiky.

Minimální hodnota pro zobrazení grafu nebo rafiky.

Název WiFi, ke které se bude PicoInk připojovat v případě MQTT.

Heslo WiFi. Podporované je pouze WPA2 šifrování nebo otevřená síť - v takovém případě zůstane parametr prázdný.

Možnost statické IP PicoInku ve formátu CIDR. V případě DHCP přiřazení zůstane parametr prázdný.

Adresa nebo DNS název MQTT, typicky IP Home Assistant serveru.

Jméno pro přihlášení na MQTT broker, typicky jméno uživatele HA.

Heslo pro přihlášení na MQTT broker, typicky heslo uživatele HA.

Název zařízení (součást topic) - v HA pojmenování entit.

V případě vyplnění jména zařízení zde, PicoInk zasílá naměřená data pomocí BLE advertisment zpráv ve formátu BT-home.

Poté, co jsou parametry nastaveny a zkontrolovány na displeji, klikneme na SAVE AND RESTART a poté zavřeme stránku. Zařízení se zrestartuje do běžného provozu s promítnutými změnami.

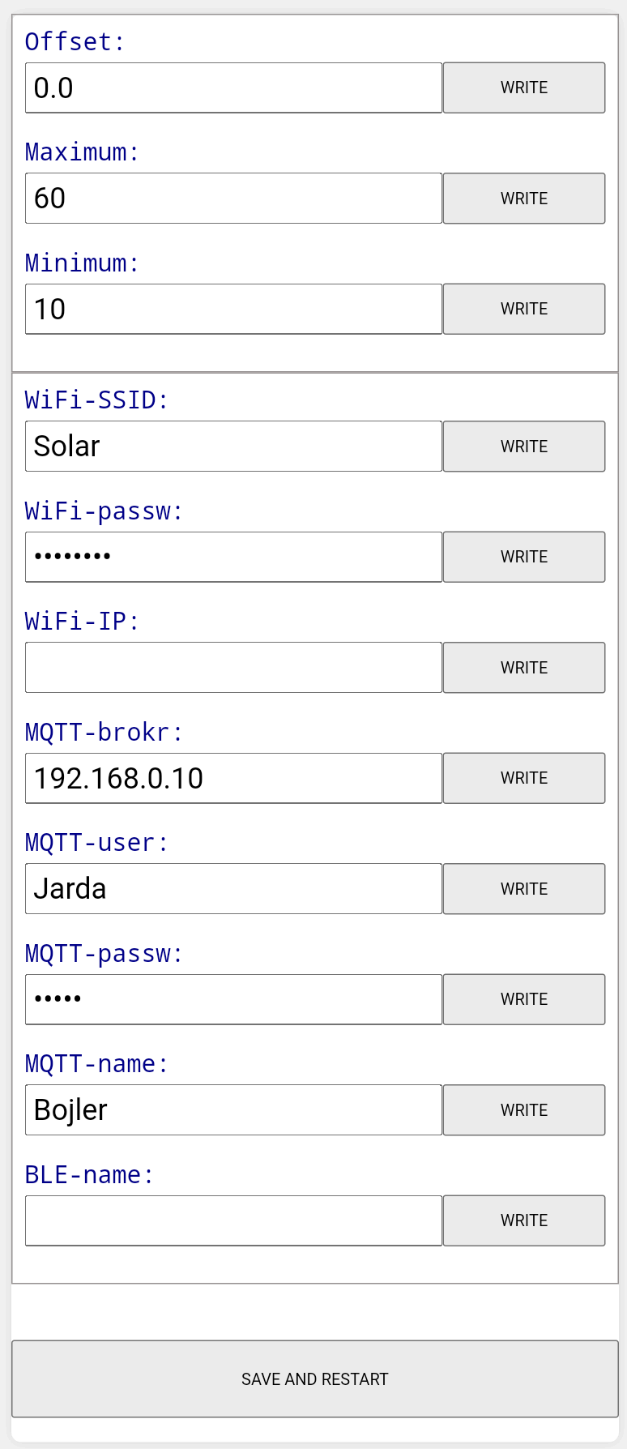
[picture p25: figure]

Pokud by nastaly jakékoliv potíže nebo potřeba veškeré změny stornovat a vrátit se zpět do původního stavu, stačí krátce stlačit levé tlačítko SETUP, zařízení se restartuje do běžného režimu a po zhasnutí stavové LED lze začít s nastavením znovu.
V případě volby WiFi MQTT a Home Assistant systému, pokračujte dále testovacím režimem!

# Testovací režim:

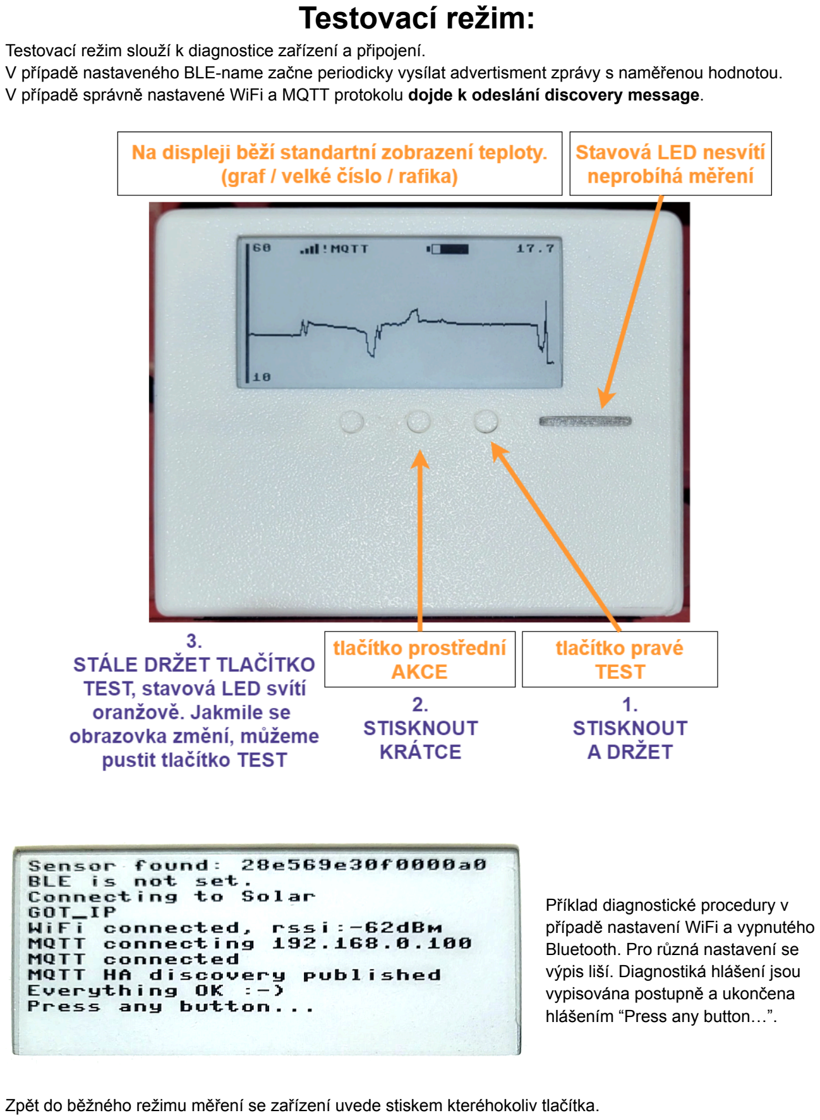
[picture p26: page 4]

Testovací režim slouží k diagnostice zařízení a připojení.
V případě nastaveného BLE-name začne periodicky vysílat advertisment zprávy s naměřenou hodnotou. V případě správně nastavené WiFi a MQTT protokolu dojde k odeslání discovery message.

Příklad diagnostické procedury v případě nastavení WiFi a vypnutého Bluetooth. Pro různá nastavení se výpis liší. Diagnostiká hlášení jsou vypisována postupně a ukončena hlášením “Press any button…”.

Zpět do běžného režimu měření se zařízení uvede stiskem kteréhokoliv tlačítka.

# Přepínání obrazovek:

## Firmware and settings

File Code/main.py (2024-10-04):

from measurement import batt_voltage, voltage_to_soc

battery_voltage = batt_voltage()
if battery_voltage < 2.6:                                   # turn off immediatelly to prevent draining battery
    from machine import Pin
    Pin(9, Pin.OUT).value(1)


if battery_voltage < 2.7:                                 # show battery dead screen then turn off
    from gpio_definitions import DONE_PIN, RED_LED
    from lib.display import screens
    from lib.templates import Low_batt_image
    from time import sleep_ms

    screens.widgets.clear()
    screens.widgets.image(Low_batt_image)
    screens.eink.show(screens.widgets.img, partial=False)
    sleep_ms(100)
    RED_LED.value(1)
    screens.eink.deep_sleep()
    sleep_ms(100)
    RED_LED.value(0)
    DONE_PIN.value(1)
    sleep_ms(1_000)
    screens.eink.epd_hw_init()


from gpio_definitions import BTN_1, BTN_2, BTN_3, GREEN_LED, DONE_PIN, RED_LED
from time import sleep_ms
if not BTN_1.value() and not BTN_2.value():
    count_down = 5
    while not BTN_1.value() and not BTN_2.value():
        print(count_down)
        count_down -= 1
        sleep_ms(1000)
        if count_down < 0:
            from lib.display import screens
            import os
            from machine import reset
            screens.widgets.tiny_text("FACTORY RESET?", 80, 50)
            screens.widgets.tiny_text("YES", 75, 110)
            screens.widgets.tiny_text("NO", 185, 110)
            screens.eink.show(screens.widgets.img, partial=False)
            def factory_reset():
                def delete_files(path):
                    try:
                        for entry in os.ilistdir(path):
                            entry_name = entry[0]
                            full_path = path + '/' + entry_name
                            try:
                                if os.stat(full_path)[0] & 0x4000:  # 0x4000 is flag for directory
                                    delete_files(full_path)  # Rekurzivly call this function
                                elif entry_name.endswith('.json') or entry_name.endswith('.dat'):
                                    os.remove(full_path)
                                    print("Deleted:", full_path)
                            except OSError as e:
                                print("Delete error {}: {}".format(full_path, e))
                    except OSError as e:
                        print("Reading error {}: {}".format(path, e))
                delete_files("/")

            buttons_released = False
            while True:
                if BTN_1.value() and BTN_2.value():
                    buttons_released = True
                t = 0
                if buttons_released:
                    while not BTN_1.value():
                        if t > 10:
                            factory_reset()
                            sleep_ms(100)
                            reset()
                        t += 1
                        sleep_ms(10)

                    if not BTN_2.value():
                        reset()


# Start Wireless ASAP
from nonvolatile import Settings, settings_save, settings_load
settings_load()
wifi_active = Settings["WiFi-SSID"]
if wifi_active:
    from lib.wireless.sta import STA, wait_for_wifi_connection, wifi_connect
    wifi_connect()
ble_active = Settings["BLE-name"]
if ble_active:
    from lib.wireless.ble_advert import ble_advert, ble


from lib.display import screens
from sensor import sensor

if __name__ == '__main__':
    device_run = True
    full_refresh = False

    bat_soc = voltage_to_soc(battery_voltage)

    if not BTN_1.value():
        from modes.mode_setup import start_setup
        start_setup("PICOINK", battery_voltage)

    elif not BTN_2.value():
        import modes.mode_testing as testing
        screens.clear_display()
        if testing.sensor_scan():
            testing.ble_try_advertising(bat_soc)
            if testing.check_settings():
                if testing.check_wifi():
                    sleep_ms(100)
                    if testing.check_mqtt():
                        sleep_ms(100)
                        if testing.try_ha_discovery():
                            testing.show_success()
        del testing
        while BTN_1.value() and BTN_2.value() and BTN_3.value():
            sleep_ms(100)
        full_refresh = True

    elif not BTN_3.value():
        Settings["widget"] += 1
        if Settings["widget"] > 2:
            Settings["widget"] = 0
        settings_save()
        sleep_ms(1000)
        full_refresh = True

    if device_run:
        from modes.mode_regular import load_show_save
        while True:
            DONE_PIN.value(0)
            rssi = False
            mqtt_ok = False
            sensor_ok = load_show_save(full_refresh, bat_soc, sensor)
            sensor.last_values["soc"] = bat_soc
            if wifi_active:
                if sensor_ok:
                    rssi = wait_for_wifi_connection()
                else:
                    STA.disconnect()
                    rssi = None
                if rssi:
                    screens.widgets.signal_indicator(rssi)
                    screens.eink.show(screens.widgets.img, partial=True)
                    from lib.wireless.ha import send_state, connect_mqtt, MQTT
                    if connect_mqtt():
                        sensor.last_values["signal"] = rssi
                        if not send_state(**sensor.last_values):
                            screens.widgets.mqtt_indicator()
                            screens.eink.show(screens.widgets.img, partial=True)
                        MQTT.wait_msg()
                        MQTT.disconnect()
                        sleep_ms(200)
                        mqtt_ok = True
                    else:
                        screens.widgets.mqtt_indicator()
                        screens.eink.show(screens.widgets.img, partial=True)
                STA.disconnect()

            if ble_active and sensor_ok:
                ble_advert(sensor.get_ble_characteristics())
                sleep_ms(500)
                ble.gap_advertise(None)

            if wifi_active:
                sleep_ms(1000)

            if sensor_ok and bat_soc > 10 and ((rssi and mqtt_ok) or not wifi_active):
                GREEN_LED.value(1)
            else:
                RED_LED.value(1)

            screens.eink.deep_sleep()
            sleep_ms(100)
            GREEN_LED.value(0)
            RED_LED.value(0)
            DONE_PIN.value(1)
            sleep_ms(10_000)

            if wifi_active:
                wifi_connect()
                # wifi_active = wifi_connect()

            full_refresh = False

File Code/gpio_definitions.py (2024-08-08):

from machine import Pin, ADC, SPI


# display WeAct
# 1 Busy    purple
# 2 Res     orange
# 3 D/C     white
# 4 CS      blue
# 5 SCL     green
# 6 SDA     yellow
# 7 GND     black
# 8 VCC     red
BUSY_PIN = Pin(10, Pin.IN, Pin.PULL_UP)
RST_PIN = Pin(11, Pin.OUT)
DC_PIN = Pin(12, Pin.OUT)
CS_PIN = Pin(13, Pin.OUT)
SCL_PIN = Pin(14)  # SCL=SCK
SDA_PIN = Pin(15)  # SDA=MOSI
SPI_NUM = 1
SPI_DISPLAY = SPI(SPI_NUM, baudrate=1_000_000, sck=SCL_PIN, mosi=SDA_PIN)
# DEFAULT SPI DECLARATION:
# SPI0 - sck=Pin(18), mosi=Pin(19), miso=Pin(16)
# SPI1 - sck=Pin(10), mosi=Pin(11), miso=Pin(8)

# tp5110
# DONE_PIN = Pin(0, Pin.OUT)
DONE_PIN = Pin(9, Pin.OUT)

# analog
Pin(28, Pin.OPEN_DRAIN, None)
BATT_ADC = ADC(28)
TEMPER_ADC = ADC(4)

# leds
ONBOARD_LED = Pin('LED', Pin.OUT)
GREEN_LED = Pin(22, Pin.OUT)
RED_LED = Pin(17, Pin.OUT)

# buttons
BTN_1 = Pin(19, Pin.IN, Pin.PULL_UP)
BTN_2 = Pin(18, Pin.IN, Pin.PULL_UP)
BTN_3 = Pin(16, Pin.IN, Pin.PULL_UP)

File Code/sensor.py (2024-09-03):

# _____________________DS18X20_____________________________________________________

from sensors.ds18b20 import DS18B20
from machine import Pin
sensor = DS18B20(Pin(0), filename="sensors/ds18b20_1.json")

# _____________________SCD4X_____________________________________________________

# from machine import I2C, Pin
# from sensors.scd4x import SCD4X
#
# Pin(8, Pin.OUT).value(1)
# Pin(9, Pin.OUT).value(0)
#
# I2c = I2C(1, scl=Pin(7), sda=Pin(6), freq=400_000)
# sensor = SCD4X(I2c)

# _______________________SOIL MOISTURE_________________________________________)

# from machine import ADC
# from sensors.soil_moisture import SoilMoisture
#
# adc = ADC(26)
# sensor = SoilMoisture(adc, "sensors/moisture_1.json")

# _____________________DHT22_____________________________________________________
#
# from machine import Pin
# from sensors.dht22 import PicoDHT22
# from time import sleep_ms
#
#
# Pin(9, Pin.OUT).value(True)
# Pin(6, Pin.OUT).value(False)
# dht_data = Pin(8, Pin.IN, Pin.PULL_UP)
# sleep_ms(1100)
# sensor = PicoDHT22(dataPin=dht_data, filename="sensors/dht22_1.json")

# _____________________SHT4X_____________________________________________________
#
# from machine import I2C, Pin
# from sensors.sht4x import SHT4X
#
# Pin(8, Pin.OUT).value(0)
# Pin(9, Pin.OUT).value(9)
#
# I2c = I2C(1, scl=Pin(7), sda=Pin(6), freq=400_000)
# sensor = SHT4X(I2c, filename="sensors/sht41.json")

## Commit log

2024-08-07 Web skin and Gauge screen
    [BoxV2.FCStd, Display+buttons+bottom.step, Display-frame.FCStd]
2024-08-13 sensor fault - no crash
    [main.py, mode_regular.py]
2024-08-14 Rename Code Folder
    [Back.FCStd, Back.step, Back_alone.FCStd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]
2024-08-15 mqtt fail indicator
    [Bojlersnap_with_curve.step, BoxV2.step]
2024-08-21 Some 3D modeling
    [Back_alone.FCStd, Bojlersnap_with_curve.step, BoxV2.FCStd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]
2024-09-03 some modeling
    [LightGuide.FCStd, LightGuide.step, Modul-bojler_horizontal_V2.3mf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]
2024-09-22 more sources
    [Horizontal_complete.3mf, Vertical_complete.3mf]
2024-09-26 Different diameters
    [Modul-drazice_524_horizontal.FCStd, Modul-drazice_524_horizontal.step, Modul-drazice_524_vertical.FCStd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]
2024-09-26 Springs update
    [Modul-drazice-spring.step, Modul-drazice-spring_42.FCStd, Modul-drazice-spring_42.step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]
2024-09-30 1k resistor
2024-09-30 Some adjusting
    [Main_body.FCStd, Main_body.step, Verticals_524.3mf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]
2024-10-04 always rise done pin
2024-10-05 524x33 modul
    [Battery_cover.FCStd, Battery_cover.step, Modul-drazice_524x33_vertical.FCStd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]
2024-10-22 more models
    [Horizontal_complete.3mf, Modul-drazice_524x33_vertical.3mf, Modul-drazice_670_vertical.FCStd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]
2024-10-27 3D merge to 3mf
    [Battery_cover.3mf, Battery_cover.FCStd, Battery_cover.step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]
2024-10-27 3D cleaning up
    [Battery_cover.3mf, Battery_cover.step, Display_holder.step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]
2024-10-27 Printing instructions
2024-11-10 OKH 100 NTR module
    [Modul-drazice_1650x30_OKH 100 NTR.FCStd, Modul_Drazice_BambuStudio.3mf]
